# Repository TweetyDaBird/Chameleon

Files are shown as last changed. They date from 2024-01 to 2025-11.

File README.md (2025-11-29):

# The Fat Chameleon 

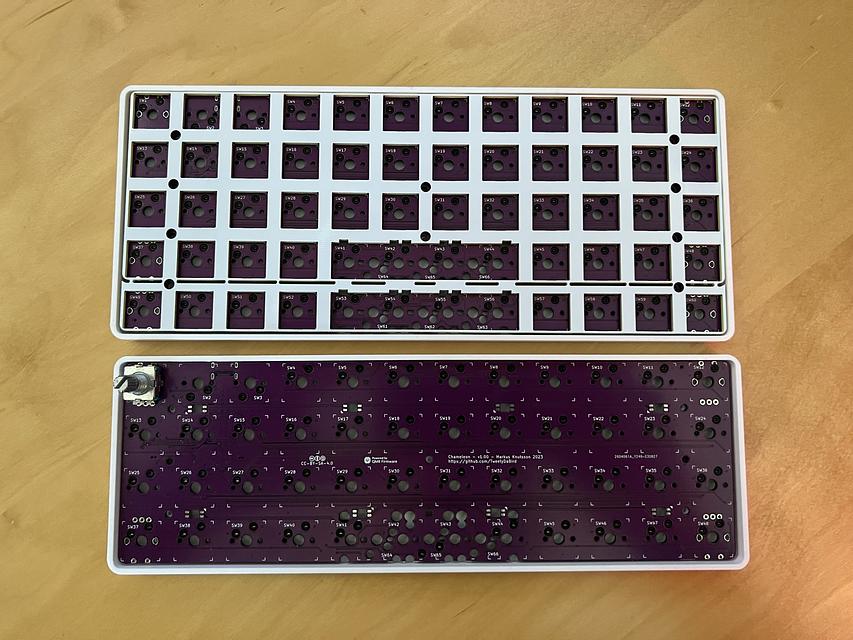
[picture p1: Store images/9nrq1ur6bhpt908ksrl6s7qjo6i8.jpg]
Chameleon


## Features
**Chameleon is a grid type orthogonal keyboard with two optional layouts in one single PCB.** Being able to break off the bottom row allows both a 5x12 layout similar to the popular Preonic and a 4x12 layout similar to the equally popular little brother Planck on the same PCB. 

Using the more common 19.05 mm grid spacing (vs Preonic & Planck's unique 19 mm) this PCB fit's several popular 'aftermarket' keyboard cases intended for JJ40/JJ50 and BM40 PCB's without modification. (Please read below!)

Being fully hot-swap and with PCB mounted stabilizers, Chameleon adds support for up to four encoders and a bottom row allowing either a single stabilized 2u key or two 2u keys in the middle, allowing for a layout that suits most users. If used as a 5 row keyboard, the bottom encoders can alternatively be placed at the edges on the second row, but **not more than one per corner.** 

The Chameleon features 8 bottomfacing RGB LEDs for underglow effects or to be used for layer indication or similar. 

**Please Note! This PCB does NOT fit a Planck/Preonic case! You will need a different case to complete the build!**

### Main Features:
* QMK and VIAL compatible, fully programmable keyboard**
* RP2040 MCU, Dual-core Arm Cortex M0+ processor, flexible clock running up to 133 MHz
* 264KB of SRAM, and 4MB of on-board Flash memory
* USB-C connector, (USB 1.1 device and host support)
* Low-power sleep and dormant modes
* Drag-and-drop programming using mass storage over USB
* Kaihl hot-swap sockets for Cherry MX compatible switches (3 & 5-pin)
* Cherry Style PCB mounted stabilizers
* Two main layouts:
	* 5x12 with 58 to 60 keys
	* 4x12 with 46 to 48 keys (Break off bottom row) 
* Configurable bottom row:
	* Full 1u grid
	* 1x centered, stabilized 2u key
	* 2x centered,  stabilized 2u keys

### Optional add-ons:
* Support for up to 4 rotary encoders **(one encoder per corner)**
* Optional RGB underglow (8x SK6812 mini-e)
* FR4 Front plate (FR4 material, same as PCB), with full layout options (Black / White). This is designed to fit most/all existing cases of a tray (or burger) mounting type, 3D printed or CNC. Se below for listed tested cases.

**These options requires additional components not included in this listing and sold separately.**

## Assembly
**Little or no tools at all needed!** The PCB can be delivered fully soldered and ready to use, either as a full matrix, or with your selection of rotary encoders (encoders need to be added to the order), or as a "DIY Kit" with the hotswap sockets for the 6 encoder positions not soldered.

The 8 optional RGB LED's needs to be soldered in place if used. (These are pre-soldered together with the encoders/hot-swap sockets at no extra cost, if that option is selected and all parts are purchased in the same order).

# Case & Plate
**The design is made to fit any existing cases for JJ40/JJ50 & BM40 both CNC and 3D printed.** This means that existing cases with an *integrated* plate is then limited to the layout options supported by that case/plate even if the PCB supports more layouts. 

#### Cases verified to work:

- [JJ50 Aluminium & Acrylic Case](https://kprepublic.com/collections/jj50-50/products/anodized-aluminium-case-for-jj50-50-custom-keyboard-acrylic-diffuser-rotary-brace-similar-with-preonic)
- [JJ50 Stainless Steel Case](https://kprepublic.com/collections/jj50-50/products/stainless-steel-bent-case-enclosed-case-for-jj50-jj50-50-custom-keyboard-acrylic-panels-acrylic-panel-diffuser-si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)
- [JJ40 Aluminium Tray Case](https://kprepublic.com/products/anodized-aluminium-jj40-bm40-flat-case-metal-feet-black-sliver-grey-for-40-mini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)
- [JJ40 Aluminium & Acrylic Case](https://kprepublic.com/products/anodized-aluminium-case-for-jj40-40-custom-keyboard-acrylic-panels-acrylic-diffuser-jj40-rotary-brace-supporter-for-planck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)
- [Poseidon PSD40 Case Anodized](https://kprepublic.com/products/poseidon-psd40-case-anodized-aluminium-case-for-custom-mechanical-keyboard-black-siver-grey-blue-red-for-jj40-bm40-bm40-rgb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) 
- [Poseidon PSD40 Case Electonplated](https://kprepublic.com/products/kp-poseidon-psd40-case-electrophoresis-cnc-case-for-custom-mechanical-keyboard-yellow-purple-cyan-white-for-jj40-bm40-bm40-rgb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)

*Mounting hardware is associated with the case, and not delivered with the Chameleon PCB and Plate.

## Front Plate
**A front plate in FR4 (PCB core material) is available as an add-on, but may not fit all cases.** To be as much a "one size fit's all" plate, this plate has rounded corners, which may leave gaps in the corners on some cases.

## 3D-print a case
**This is an adaptation of the Olkb Low Pro, ie low profile case for the Planck**, slightly re-designed to fit the 'normal' key spacing of the JJ40/JJ50 PCB and available as two designs to fit either the Planck or Preonic layout. Fully compatible with the FR4 front plate.
- [JJ50 - "Preonic" LoPro case](https://github.com/TweetyDaBird/Chameleon/blob/Development/JJ50_BM50_low_pro.zip)
- [JJ40 & BM40 - "Planck" LoPro case](https://github.com/TweetyDaBird/Chameleon/blob/Development/JJ40_BM40_low_pro.zip)

#### Examples of a 3D-printed case in white (Including the top image):
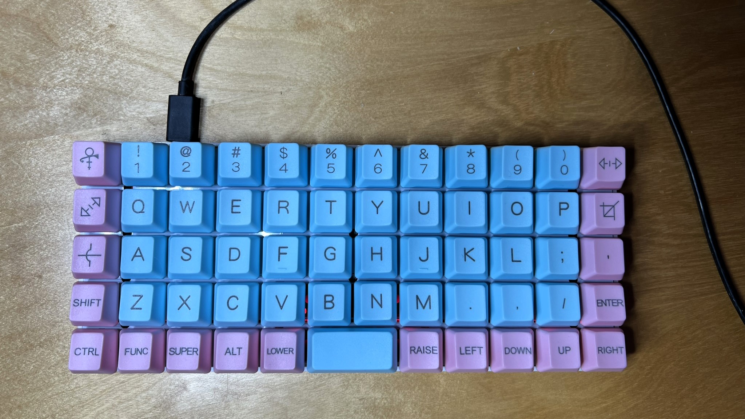
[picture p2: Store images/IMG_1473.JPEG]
Built Chameleon

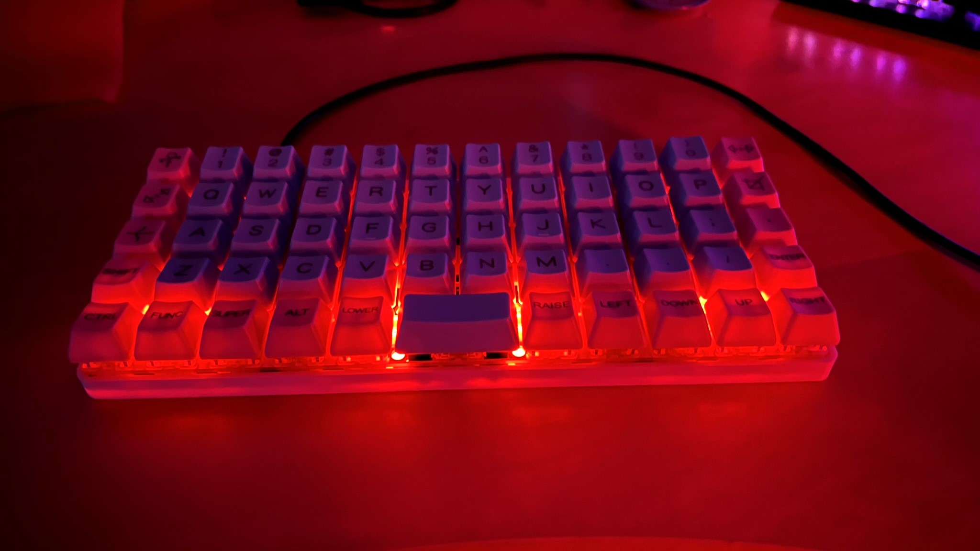
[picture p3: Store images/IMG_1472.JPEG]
Lit Chameleon


## Sandwich type case/plates
A full sandwich type case in FR4 material will be added at a later date for those interested, but is for now WIP.

# Making Chameleon yourself
**Chameleon is open source / open hardware, and can be manufactured by anyone. The release contains all the neccesary files like parts lists, positions files etc for a full PCB/SMT production.** 

The formatting and files are geared towards [JLCPCB](http://jlcpcb.com), but never tested as such, as I only manufacture the PCB then do the assembly myself (at least until this reaches a volume justifying full SMT production).

The components are small enough that you would have to be highly skilled to attempt to assemble this either as hand soldered, or small scale/DIY SMT. I would highly recommend ordering the PCB as fully assembled unless you know you have the neccesary skill-set.

## Buy a kit!
I sell complete kits, making it easy to build your keyboard, and it also supports prototypes for new wacky ones. 



## Discord for build help and discussions!

<a href="https://discord.gg/G6QzcJQUnm">Discuss on Discord</a>

# License

[][cc-by-sa] - This work is licensed under a
[Creative Commons Attribution-ShareAlike 4.0 International License][cc-by-sa].

[cc-by-sa]: http://creativecommons.org/licenses/by-sa/4.0/
[cc-by-sa-shield]: https://img.shields.io/badge/License-CC%20BY--SA%204.0-lightgrey.svg

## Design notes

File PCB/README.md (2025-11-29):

# Chameleon PCB

## Change Log:
- v1.00 - Initial Release

- v1.01 - Second Release
  - Corrected RGB
  - Tweaked outline for easier removal of bottom row
  
- v1.11 - Third Release
  - Corrected USB Port position
  
- v1.20 - Third Release
  - Corrections to silkscreen.
<<<<<<< HEAD
  - Marking the spacer mounting holes for Planck/Preonic
=======
  - Marking the spacer mounting holes for Planck/Preonic
  - Marking Sockets for layout.
  - Added socket warning.
  - Add CE/RoHS marking.

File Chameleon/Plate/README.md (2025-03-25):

# Chameleon Front Plate
**An FR4 material front plate suited to most tray type cases.**

## Change Log:
- v1.00 - Initial release
- v1.01 - Tweaked outline for easier removal of bottom row 
- v1.10 - Further tweaked outline for easier removal of bottom row

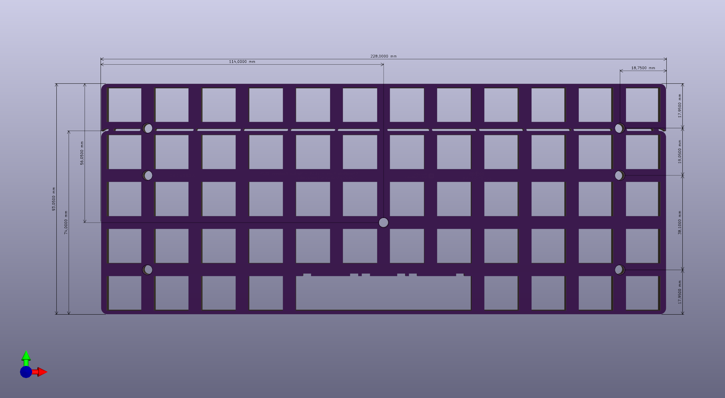
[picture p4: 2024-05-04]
Chameleon/Plate/v1.10/Chameleon Plate v1_10.png

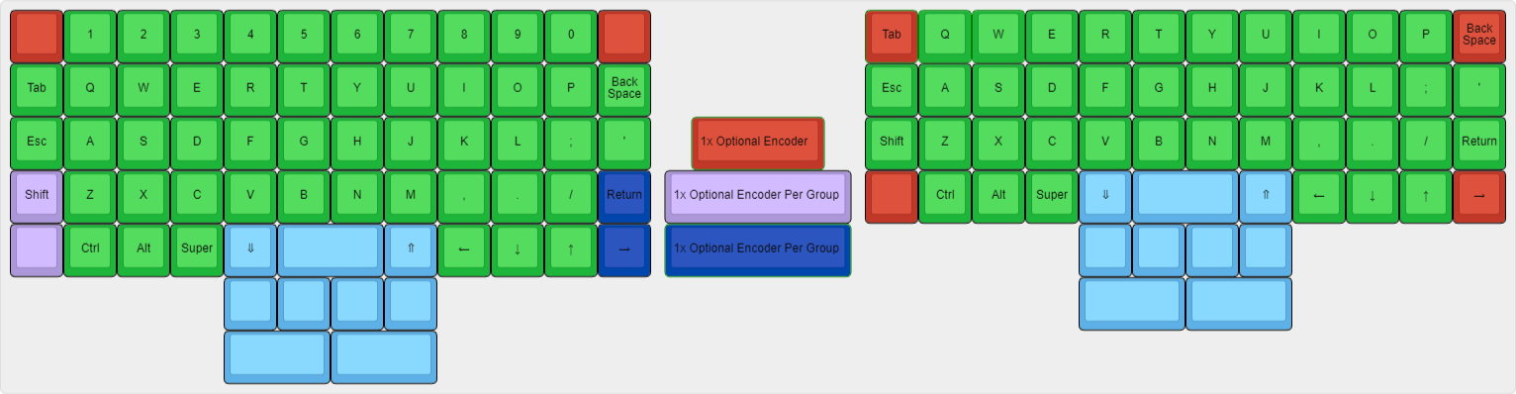
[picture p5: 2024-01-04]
Store images/Chameleon 4x12 & 5x12.png

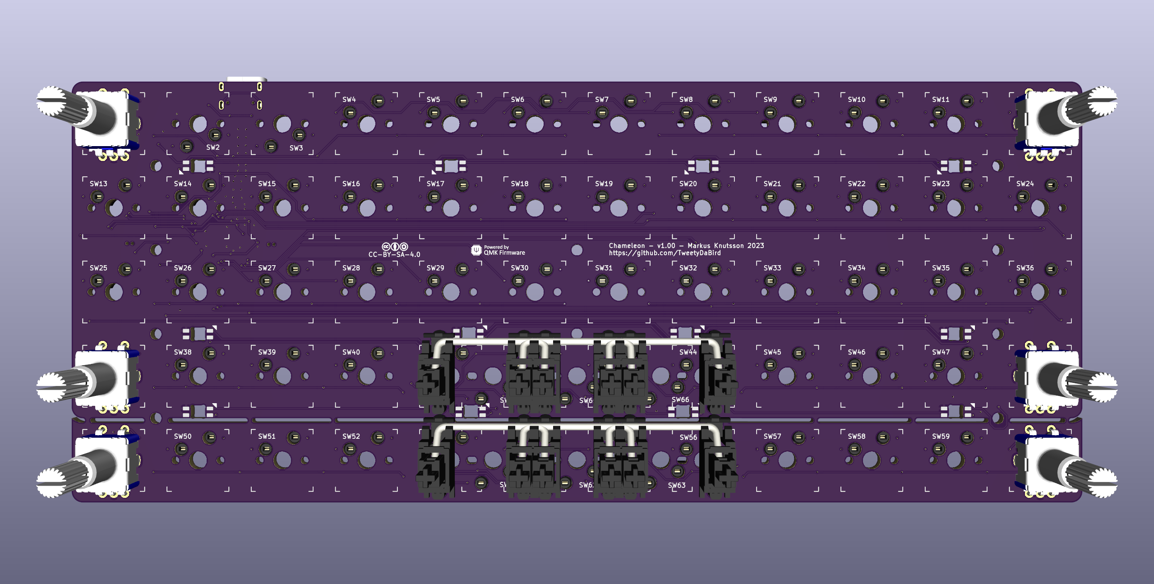
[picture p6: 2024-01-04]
Store images/Chameleon v1_0_front.png

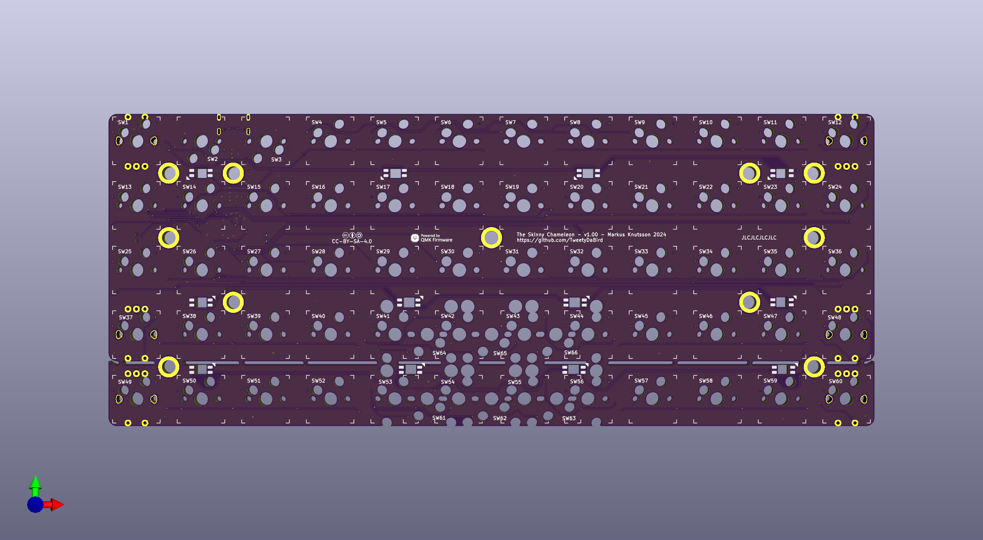
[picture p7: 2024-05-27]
Store images/Skinny Chameleon Front.png

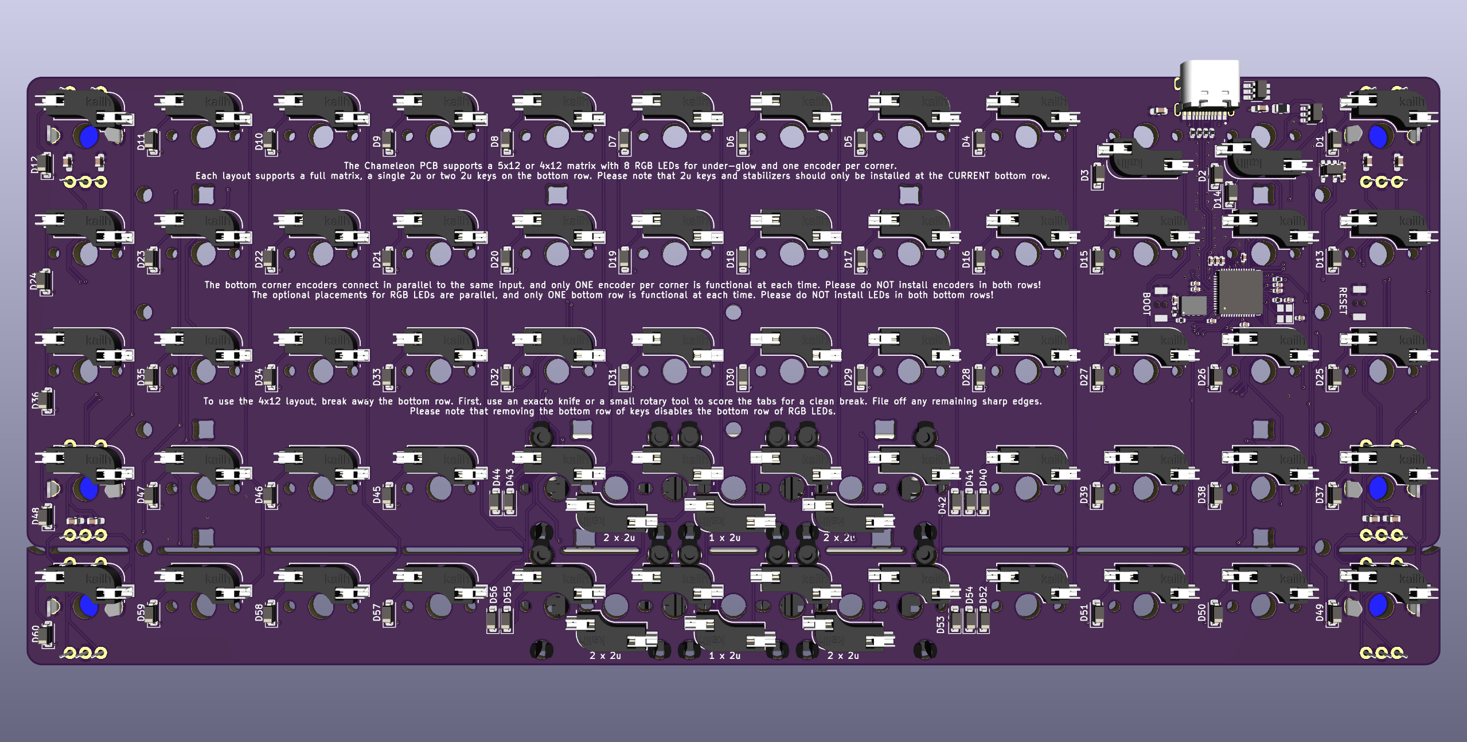
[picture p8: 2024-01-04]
Store images/Chameleon v1_0_back.png

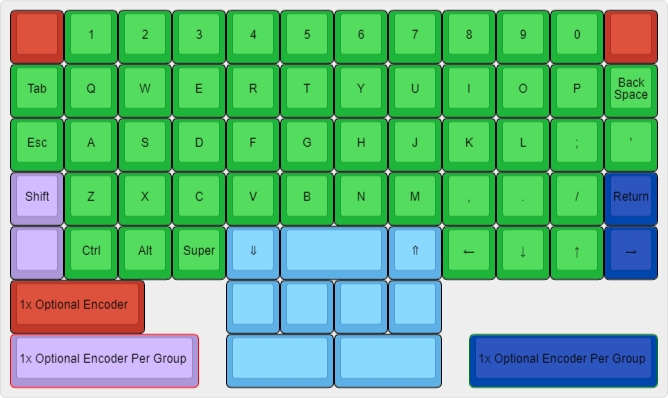
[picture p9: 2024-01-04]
Store images/Chameleon 5x12.png

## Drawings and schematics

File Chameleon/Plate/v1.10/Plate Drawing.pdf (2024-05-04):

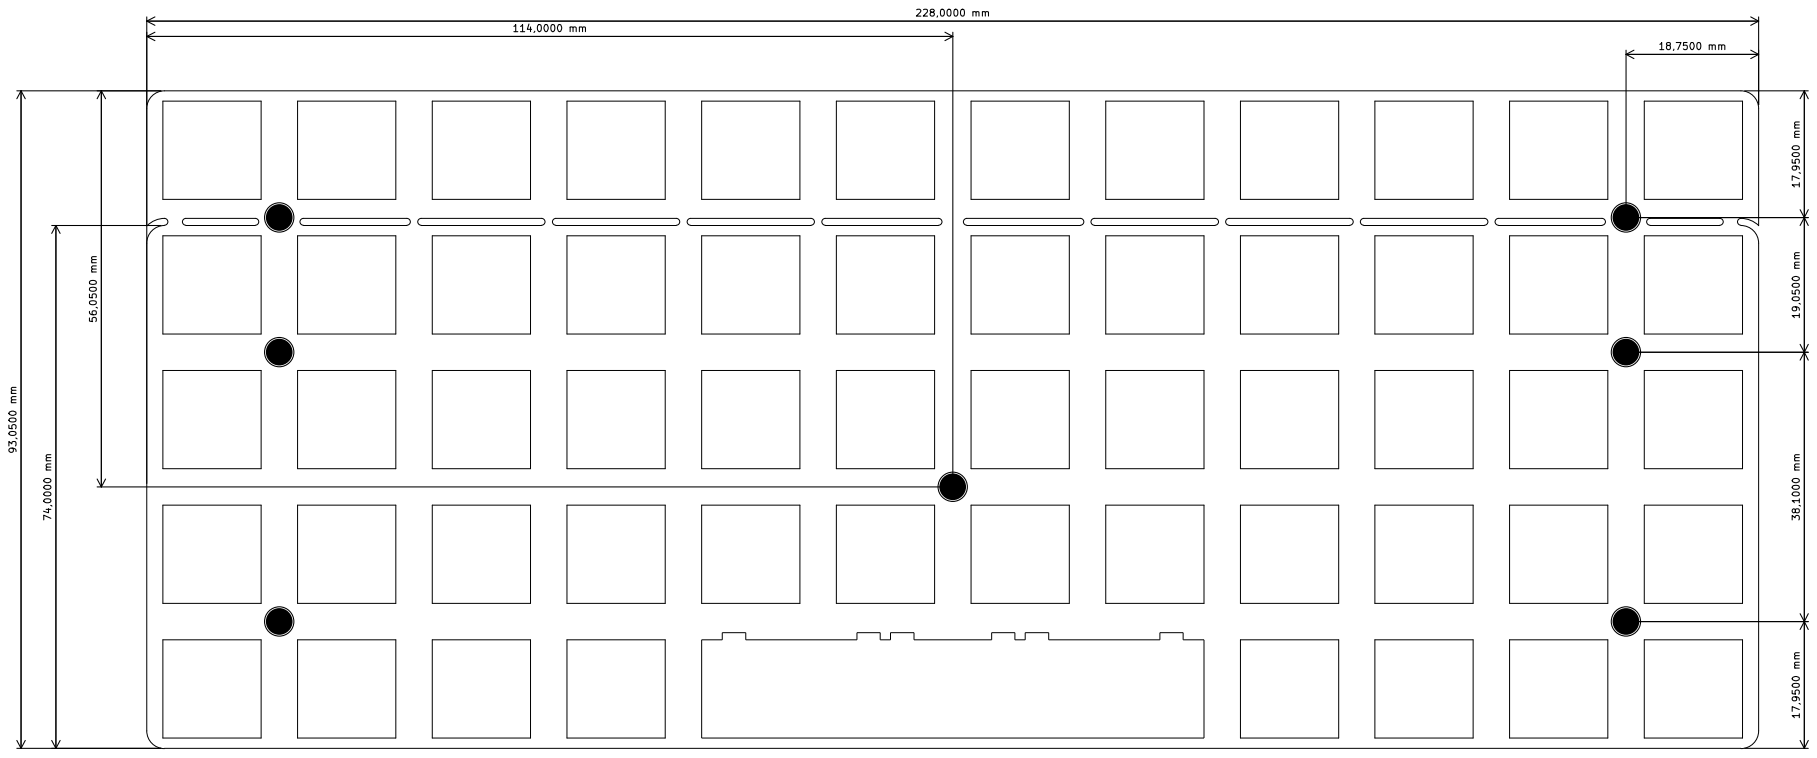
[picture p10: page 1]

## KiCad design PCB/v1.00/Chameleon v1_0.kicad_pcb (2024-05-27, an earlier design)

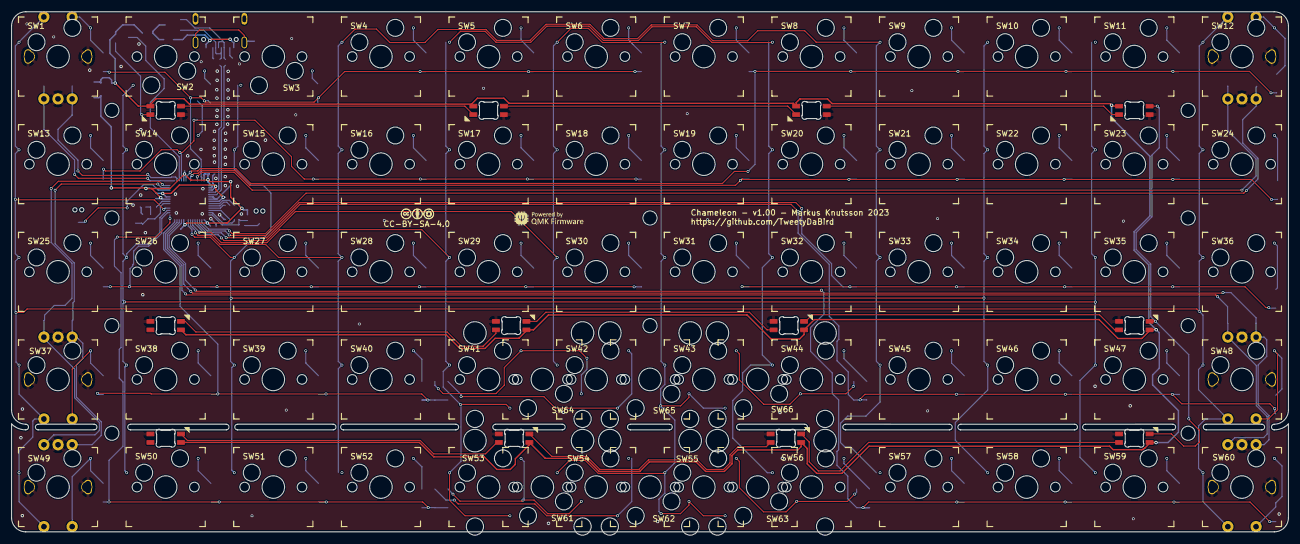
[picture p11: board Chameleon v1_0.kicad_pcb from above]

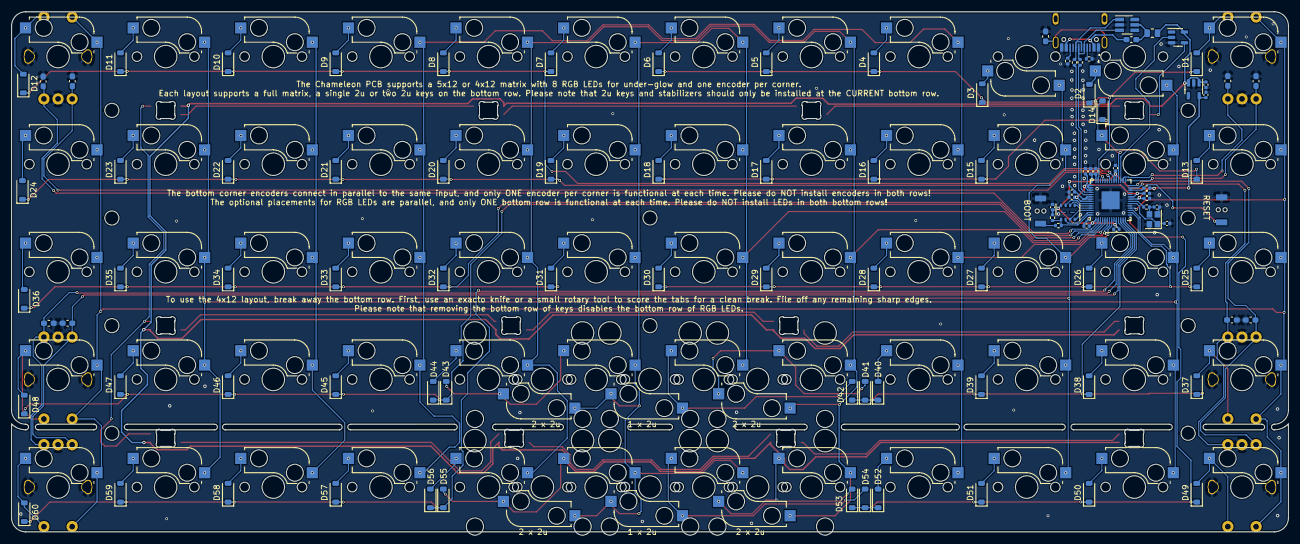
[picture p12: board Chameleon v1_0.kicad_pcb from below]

Board: 2 copper layers, 226.0 x 92.0 mm, 205 parts (115 on the bottom side), 120 nets.

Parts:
C1, C8, C11, C12: 1u; C_0402_1005Metric
C2, C3, C4, C5, C6, C7, C9, C10, C13: 100n; C_0402_1005Metric
C14, C15: 30p; C_0402_1005Metric
C16, C17, C18, C19, C20, C21, C22, C23: 100nF; C_0603_1608Metric_Pad1.08x0.95mm_HandSolder
D1, D2, D3, D4, D5, D6, D7, D8, D9, D10, D11, D12, D13, D14, D15, D16, D17, D18, D19, D20, D21, D22, D23, D24, D25, D26, D27, D28, D29, D30, D31, D32, D33, D34, D35, D36, D37, D38, D39, D40, D41, D42, D43, D44, D45, D46, D47, D48, D49, D50, D51, D52, D53, D54, D55, D56, D57, D58, D59, D60: 1N4148W; D_SOD-123
ENC1, ENC2, ENC3, ENC4, ENC5, ENC6: RotaryEncoder_Switch; Encoder_Alps_EC11E_Small
F1: 500 mA; R_0805_2012Metric
FB1, FB2: Ferrite Bead; C_0603_1608Metric_Pad1.08x0.95mm_HandSolder
H1, H2, H3, H4, H5, H6, H7, H8, H9, H10: Spacer_PCB; Spacer Plate hole
J1: USB_C_Receptacle_USB2.0; HRO_TYPE-C-31-M-12
Logo1: CC-BY-SA-4.0; CC_BY_SA_40_tiny
Logo2: QMK_Logo; Powered_by_QMK
R1, R2: 5.1K; R_0402_1005Metric
R3, R7: 10k; R_0402_1005Metric
R4, R10: 1k; R_0402_1005Metric
R5, R6: 27R; R_0402_1005Metric
RGB1, RGB2, RGB3, RGB4, RGB5, RGB6, RGB7, RGB8, RGB9, RGB10, RGB11, RGB12: SK6812MINI-E; RGB_SK6812MINI-E
ST1, ST2, ST3, ST4, ST5, ST6: Stabilizer_2u_MX; Stabilizer_Cherry_MX_2.00u
SW1, SW12, SW37, SW48, SW49, SW60: SW_MX_HotSwap_FOR ENCODER
SW2, SW3, SW4, SW5, SW6, SW7, SW8, SW9, SW10, SW11, SW13, SW14, SW15, SW16, SW17, SW18, SW19, SW20, SW21, SW22, SW23, SW24, SW25, SW26, SW27, SW28, SW29, SW30, SW31, SW32, SW33, SW34, SW35, SW36, SW38, SW39, SW40, SW41, SW42, SW43, SW44, SW45, SW46, SW47, SW50, SW51, SW52, SW53, SW54, SW55, SW56, SW57, SW58, SW59, SW61, SW62, SW63, SW64, SW65, SW66: SW_MX_HotSwap
SW67, SW68: SW_Push; YTSA010
U1: SPX3819M5-L-3-3/TR; SOT-23-5
U2: W25Q32JVUUIQ; USON-8_4x3mm_P0.8mm
U3: RP2040; QFN-56-1EP_7x7mm_P0.4mm_EP3.2x3.2mm
U4: SN74LV1T34DBV; SOT-23-5
U5: SRV05-4; SOT-23-6_Handsoldering
Y1: TXM12M0004252LBCEO00T; Crystal_SMD_2520-4Pin_2.5x2.0mm

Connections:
+1V1: C8.1, C9.1, C10.1, U3.23 (DVDD), U3.45 (VREG_VOUT), U3.50 (DVDD)
+3V3: C1.1, C2.1, C3.1, C4.1, C5.1, C6.1, C7.1, C12.1, C13.1, R3.1, R7.1, U1.5 (OUT), U2.8 (VCC), U3.1 (IOVDD), U3.10 (IOVDD), U3.22 (IOVDD), U3.33 (IOVDD), U3.42 (IOVDD), U3.43 (ADC_AVDD), U3.44 (VREG_IN), U3.48 (USB_VDD), U3.49 (IOVDD)
+5V: C11.1, F1.2, RGB1.4 (VDD), RGB2.4 (VDD), RGB3.4 (VDD), RGB4.4 (VDD), RGB5.4 (VDD), RGB6.4 (VDD), RGB7.4 (VDD), RGB8.4 (VDD), RGB9.4 (VDD), RGB10.4 (VDD), RGB11.4 (VDD), RGB12.4 (VDD), U1.1 (IN), U1.3 (EN), U4.5 (VCC)
/DN: R6.1, U3.46 (USB_DM)
/DP: R5.1, U3.47 (USB_DP)
Col_0: ENC1.S2, ENC2.S2, ENC3.S1, ENC4.S1, ENC5.S1, ENC6.S1, SW1.1, SW12.1, SW13.1, SW24.1, SW25.1, SW36.1, SW37.1, SW48.1, SW49.1, SW60.1, U3.18 (GPIO15)
Col_1: SW2.2, SW11.1, SW14.1, SW23.1, SW26.1, SW35.1, SW38.1, SW47.1, SW50.1, SW59.1, U3.17 (GPIO14)
Col_2: SW3.2, SW10.1, SW15.1, SW22.1, SW27.1, SW34.1, SW39.1, SW46.1, SW51.1, SW58.1, U3.8 (GPIO6)
Col_3: SW4.1, SW9.1, SW16.1, SW21.1, SW28.1, SW33.1, SW40.1, SW45.1, SW52.1, SW57.1, U3.7 (GPIO5)
Col_4: SW5.1, SW8.1, SW17.1, SW20.1, SW29.1, SW32.1, SW41.1, SW44.1, SW53.1, SW56.1, SW61.2, SW64.2, U3.6 (GPIO4)
Col_5: SW6.1, SW7.1, SW18.1, SW19.1, SW30.1, SW31.1, SW42.1, SW43.1, SW54.1, SW55.1, SW62.1, SW63.2, SW65.1, SW66.2, U3.5 (GPIO3)
D+: J1.A6 (D+), J1.B6 (D+), R5.2, U5.1 (IO1)
D-: J1.A7 (D-), J1.B7 (D-), R6.2, U5.3 (IO2)
ENC1: D1.2 (A), ENC1.S1, SW1.2
ENC1_A: C16.1, ENC1.A, U3.29 (GPIO18)
ENC1_B: C17.2, ENC1.B, U3.30 (GPIO19)
ENC2: D12.2 (A), ENC2.S1, SW12.2
ENC2_A: C18.1, ENC2.A, U3.39 (GPIO27_ADC1)
ENC2_B: C19.2, ENC2.B, U3.2 (GPIO0)
ENC3: D37.2 (A), ENC3.S2, SW37.2
ENC3_A: C21.2, ENC3.B, ENC5.B, U3.28 (GPIO17)
ENC3_B: C20.1, ENC3.A, ENC5.A, U3.27 (GPIO16)
ENC4: D48.2 (A), ENC4.S2, SW48.2
ENC4_A: C23.2, ENC4.B, ENC6.B, U3.13 (GPIO10)
ENC4_B: C22.1, ENC4.A, ENC6.A, U3.12 (GPIO9)
ENC5: D49.2 (A), ENC5.S2, SW49.2
ENC6: D60.2 (A), ENC6.S2, SW60.2
Earth_Protective: FB2.1, J1.S1 (SHIELD)
GND: C1.2, C2.2, C3.2, C4.2, C5.2, C6.2, C7.2, C8.2, C9.2, C10.2, C11.2, C12.2, C13.2, C14.2, C15.2, C16.2, C17.1, C18.2, C19.1, C20.2, C21.1, C22.2, C23.1, ENC1.C, ENC1.MP1 (GND), ENC1.MP2 (GND), ENC2.C, ENC2.MP1 (GND), ENC2.MP2 (GND), ENC3.C, ENC3.MP1 (GND), ENC3.MP2 (GND), ENC4.C, ENC4.MP1 (GND), ENC4.MP2 (GND), ENC5.C, ENC5.MP1 (GND), ENC5.MP2 (GND), ENC6.C, ENC6.MP1 (GND), ENC6.MP2 (GND), FB2.2, J1.A1 (GND), J1.A12 (GND), J1.B1 (GND), J1.B12 (GND), R1.1, R2.2, RGB1.2 (VSS), RGB2.2 (VSS), RGB3.2 (VSS), RGB4.2 (VSS), RGB5.2 (VSS), RGB6.2 (VSS), RGB7.2 (VSS), RGB8.2 (VSS), RGB9.2 (VSS), RGB10.2 (VSS), RGB11.2 (VSS), RGB12.2 (VSS), SW1.3, SW12.3, SW37.3, SW48.3, SW49.3, SW60.3, SW67.1, SW68.1, U1.2 (GND), U2.4 (GND), U3.19 (TESTEN), U3.57 (GND), U4.3 (GND), U5.2 (VN), Y1.2, Y1.4
unnamed: C15.1, R10.2, Y1.3
unnamed: D2.2 (A), SW2.1
unnamed: D3.2 (A), SW3.1
unnamed: D4.2 (A), SW4.2
unnamed: D5.2 (A), SW5.2
unnamed: D6.2 (A), SW6.2
unnamed: D7.2 (A), SW7.2
unnamed: D8.2 (A), SW8.2
unnamed: D9.2 (A), SW9.2
unnamed: D10.2 (A), SW10.2
unnamed: D11.2 (A), SW11.2
unnamed: D13.2 (A), SW13.2
unnamed: D14.2 (A), SW14.2
unnamed: D15.2 (A), SW15.2
unnamed: D16.2 (A), SW16.2
unnamed: D17.2 (A), SW17.2
unnamed: D18.2 (A), SW18.2
unnamed: D19.2 (A), SW19.2
unnamed: D20.2 (A), SW20.2
unnamed: D21.2 (A), SW21.2
unnamed: D22.2 (A), SW22.2
unnamed: D23.2 (A), SW23.2
unnamed: D24.2 (A), SW24.2
unnamed: D25.2 (A), SW25.2
unnamed: D26.2 (A), SW26.2
unnamed: D27.2 (A), SW27.2
unnamed: D28.2 (A), SW28.2
unnamed: D29.2 (A), SW29.2
unnamed: D30.2 (A), SW30.2
unnamed: D31.2 (A), SW31.2
unnamed: D32.2 (A), SW32.2
unnamed: D33.2 (A), SW33.2
unnamed: D34.2 (A), SW34.2
unnamed: D35.2 (A), SW35.2
unnamed: D36.2 (A), SW36.2
unnamed: D38.2 (A), SW38.2
unnamed: D39.2 (A), SW39.2
unnamed: D40.2 (A), SW40.2
unnamed: D41.2 (A), SW41.2, SW64.1
unnamed: D42.2 (A), SW42.2, SW65.2
unnamed: D43.2 (A), SW43.2, SW66.1
unnamed: D44.2 (A), SW44.2
unnamed: D45.2 (A), SW45.2
unnamed: D46.2 (A), SW46.2
unnamed: D47.2 (A), SW47.2
unnamed: D50.2 (A), SW50.2
unnamed: D51.2 (A), SW51.2
unnamed: D52.2 (A), SW52.2
unnamed: D53.2 (A), SW53.2, SW61.1
unnamed: D54.2 (A), SW54.2, SW62.2
unnamed: D55.2 (A), SW55.2, SW63.1
unnamed: D56.2 (A), SW56.2
unnamed: D57.2 (A), SW57.2
unnamed: D58.2 (A), SW58.2
unnamed: D59.2 (A), SW59.2
unnamed: FB1.1, J1.A4 (VBUS), J1.A9 (VBUS), J1.B4 (VBUS), J1.B9 (VBUS)
unnamed: J1.A5 (CC1), R1.2
unnamed: J1.B5 (CC2), R2.1
unnamed: R4.2, SW68.2
unnamed: RGB1.3 (DIN), U4.4 (Y)
unnamed: RGB1.1 (DOUT), RGB2.3 (DIN)
unnamed: RGB2.1 (DOUT), RGB3.3 (DIN)
unnamed: RGB3.1 (DOUT), RGB4.3 (DIN)
unnamed: RGB4.1 (DOUT), RGB5.3 (DIN), RGB9.3 (DIN)
unnamed: RGB5.1 (DOUT), RGB6.3 (DIN)
unnamed: RGB6.1 (DOUT), RGB7.3 (DIN)
unnamed: RGB7.1 (DOUT), RGB8.3 (DIN)
unnamed: RGB9.1 (DOUT), RGB10.3 (DIN)
unnamed: RGB10.1 (DOUT), RGB11.3 (DIN)
unnamed: RGB11.1 (DOUT), RGB12.3 (DIN)
unnamed: U2.6 (CLK), U3.52 (QSPI_SCLK)
unnamed: U2.5 (DI(IO0)), U3.53 (QSPI_SD0)
unnamed: U2.2 (DO(IO1)), U3.55 (QSPI_SD1)
unnamed: U2.3 (IO2), U3.54 (QSPI_SD2)
unnamed: U2.7 (IO3), U3.51 (QSPI_SD3)
unnamed: R4.1, R7.2, U2.1 (~CS), U3.56 (QSPI_SS)
unnamed: R3.2, SW67.2, U3.26 (RUN)
unnamed: C14.1, U3.20 (XIN), Y1.1
unnamed: R10.1, U3.21 (XOUT)
RGB: U3.31 (GPIO20), U4.2 (A)
Row_0: D1.1 (K), D2.1 (K), D3.1 (K), D4.1 (K), D5.1 (K), D6.1 (K), U3.41 (GPIO29_ADC3)
Row_1: D7.1 (K), D8.1 (K), D9.1 (K), D10.1 (K), D11.1 (K), D12.1 (K), U3.34 (GPIO22)
Row_2: D13.1 (K), D14.1 (K), D15.1 (K), D16.1 (K), D17.1 (K), D18.1 (K), U3.32 (GPIO21)
Row_3: D19.1 (K), D20.1 (K), D21.1 (K), D22.1 (K), D23.1 (K), D24.1 (K), U3.36 (GPIO24)
Row_4: D25.1 (K), D26.1 (K), D27.1 (K), D28.1 (K), D29.1 (K), D30.1 (K), U3.16 (GPIO13)
Row_5: D31.1 (K), D32.1 (K), D33.1 (K), D34.1 (K), D35.1 (K), D36.1 (K), U3.3 (GPIO1)
Row_6: D37.1 (K), D38.1 (K), D39.1 (K), D40.1 (K), D41.1 (K), D42.1 (K), U3.14 (GPIO11)
Row_7: D43.1 (K), D44.1 (K), D45.1 (K), D46.1 (K), D47.1 (K), D48.1 (K), U3.4 (GPIO2)
Row_8: D49.1 (K), D50.1 (K), D51.1 (K), D52.1 (K), D53.1 (K), D54.1 (K), U3.15 (GPIO12)
Row_9: D55.1 (K), D56.1 (K), D57.1 (K), D58.1 (K), D59.1 (K), D60.1 (K), U3.11 (GPIO8)
VBUS: F1.1, FB1.2, U5.5 (VP)

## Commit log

2023-08-24 Initial design
    [Chameleon v1_0.kicad_sch]
2023-08-27 prototype
    Tweaked to (probably) prototype status
    [Chameleon v1_0.kicad_sch]
2023-09-22 Added versioning
    [Chameleon v1_0.kicad_sch]
2023-09-22 v1.01
    - Fix silkscreen errors
    - Fix reset/boot button footprint
    - Move rightmost column of diodes for easier PCB handling
    [Chameleon Plate v1_0.kicad_pcb, Chameleon Plate v1_0.kicad_sch, Chameleon v1_0.kicad_sch]
2024-01-04 v1.10
    initial
    [Chameleon v1_10.kicad_sch]
2024-01-04 Plate v1.01
    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
    [Chameleon Plate v1_01.kicad_pcb, Chameleon Plate v1_01.kicad_sch]
2024-01-04 files in the wrong place
    [Chameleon Plate v1_0.kicad_pcb, Chameleon Plate v1_0.kicad_sch]
2024-01-04 Added plate readme
2024-01-04 Add readme/changelog to PCB folder
2024-01-04 v1.10
    added interactive bom
2024-02-09 v1.10 created BOM
2024-02-09 v1.10
    Minor correction silkscreen
    [Chameleon v1_10.kicad_sch]
2024-05-03 v1.11
    minor silkscreen correction
    [Chameleon v1_11.kicad_pcb, Chameleon v1_11.kicad_sch]
2024-05-04 Added plate drawing
2024-05-27 Skinny Chameleon
    v1.00
    [Chameleon Plate v1_0.kicad_pcb, Chameleon Plate v1_0.kicad_sch, Chameleon Plate v1_01.kicad_pcb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]
2024-06-05 Skinny Chameleon v1.1
    Fixed mounting holes
    [Skinny Chameleon.kicad_pcb, Skinny Chameleon.kicad_sch]
2024-07-25 Update README.md
    Added downloadable 3D print cases.
2024-08-16 Skinny Chamelelon v1.10
    - Updated Planck Mounting holes
    - Updated centering on USB (was centered on 19.05 spacing?)
    [Skinny Chameleon.kicad_pcb, Skinny Chameleon.kicad_sch]
2024-08-19 Split Skinny Chameleon
    Files are moved to a different Git
    [Skinny Chameleon.kicad_pcb, Skinny Chameleon.kicad_sch]
2025-03-25 Chameleon v1.20
    [Chameleon v1_11.kicad_sch, Chameleon.kicad_pcb, Chameleon.kicad_sch]
2025-11-29 Chameleon v1.20
    # Conflicts:
    # Chameleon/PCB/README.md
2025-11-29 re-ordered files
    [Chameleon Plate v1_0.kicad_pcb, Chameleon Plate v1_0.kicad_sch, Chameleon Plate v1_01.kicad_pcb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]
2025-11-29 Moved Case/Plate Designs to a separate Git
    [Chameleon Plate v1_0.kicad_pcb, Chameleon Plate v1_0.kicad_sch, Chameleon Plate v1_01.kicad_pcb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]

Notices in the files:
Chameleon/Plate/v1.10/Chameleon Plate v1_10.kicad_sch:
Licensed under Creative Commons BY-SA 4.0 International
